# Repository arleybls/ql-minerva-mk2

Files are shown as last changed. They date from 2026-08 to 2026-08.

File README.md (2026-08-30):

# Sinclair QL - Minerva MK II Reimagined (SMD edition)

A surface-mount redesign of the Minerva MK II ROM and clock board for the Sinclair QL, based on
[Alvaro Alea Fernandez's KiCad recreation](https://github.com/alvaroalea/QL_Minerva_MK2) of the
original 1990 QView board.

The board plugs into the QL's internal ROM socket. It replaces the QL's ROM with a 64 KB EPROM
holding the Minerva operating system, with Toolkit II in the upper 16 KB if you want it, and adds
a battery-backed PCF8583 real-time clock. The clock sits on an I2C port inside the ROM address
space, so the QL reads it with ordinary ROM reads.

<p>
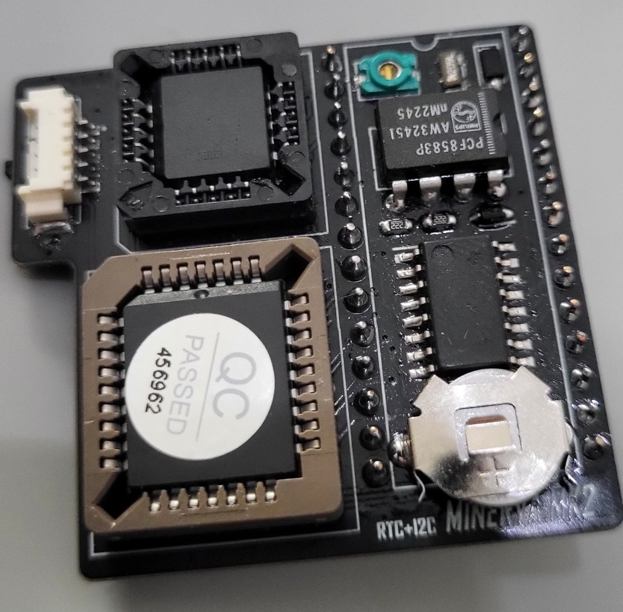
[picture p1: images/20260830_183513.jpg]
Assembled board
  
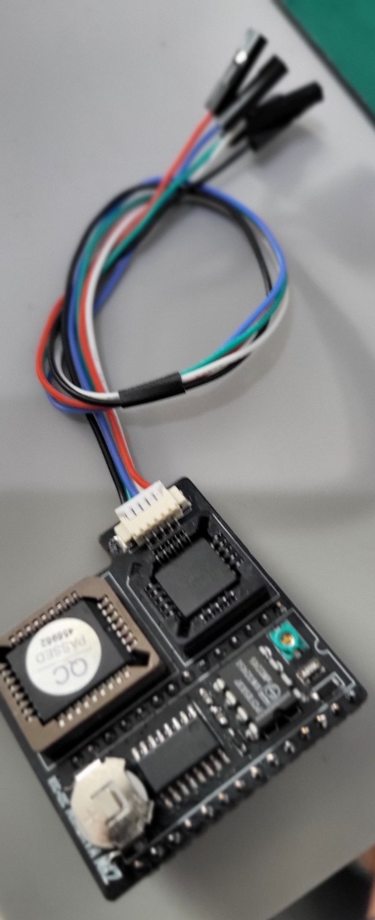
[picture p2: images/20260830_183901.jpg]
Assembled board with the I2C cable on J2
  
</p>

Left: the assembled board. Right: with the I2C cable plugged into J2.

## What is different from Alvaro's board

| | Alvaro's board | This board |
|---|---|---|
| Construction | through-hole | surface mount, 42.7 x 40.6 mm, two layers, ground pour on each side |
| EPROM | W27C512, DIP-28 socket, with the 74LS133 soldered underneath it | 27C512 in a PLCC-32 SMD socket; nothing mounted under anything |
| GAL16V8 | DIP-20 socket | PLCC-20 SMD socket, still reprogrammable |
| 13-input NAND | 74LS133, DIP-16 | SN74ALS133, SOP-16 |
| Resistors, diode, crystal, trimmer | axial, DO-35, AT310, radial trimmer | 0603, SOD-123W, FC-135, TZC3 SMD trimmer |
| Expansion header J2 | 2.54 mm pins | PicoBlade 53261 |
| Battery | external, through a two-pin header and a 120 ohm trickle-charge resistor | CR927 coin cell on the board, fed through two Schottky diodes so the cell is never charged and takes over when the QL is off |
| GAL pins 6 and 7 | pin 6 on VCC, pin 7 on /DECODE | pin 6 on SW1, pin 7 on +5 V, as the MINGAL_MH v1.10 equations require; this makes the map-in/map-out of the upper 16 KB work |
| Upper 16 KB select | JP1 solder jumper | SW1 slide switch (see below) |
| Decoupling | two capacitors | four 100 nF: at the GAL, the 74ALS133 and the EPROM on +5 V, and one at the PCF8583 on the battery rail |
| Clock chip testing | none | a small tester board and sketch (see below) |

### A switch instead of a solder jumper

Upstream JP1 was a three-pad solder jumper with its centre pad on the /DECODE net, which is the
74LS133's output. Pads 1 and 2 were bridged by default, so the jumper shorted that output to the
supply. SW1, a slide switch on its own GAL input, replaces it. SW1 selects whether the EPROM's
upper 16 KB (Toolkit II) is mapped in or left free for an external expansion ROM.

### A tester for the clock chips

`pcf8583-tester/` is a small separate board (Arduino Nano plus a DIP-8 socket) and a sketch for
checking PCF8583 chips before one is soldered in. It writes ten test patterns to all 248 bytes
of RAM, checks the clock registers, then drives the chip's oscillator input from the Nano at 100
times real speed to run the whole counter chain: minute, hour, month, leap-year rollovers, the
alarm and the timer. It prints a checklist and a pass or fail verdict in about three seconds.
Second-hand and old-stock PCF8583s vary a lot in quality, and this finds the bad ones. See
[pcf8583-tester/README.md](pcf8583-tester/README.md).

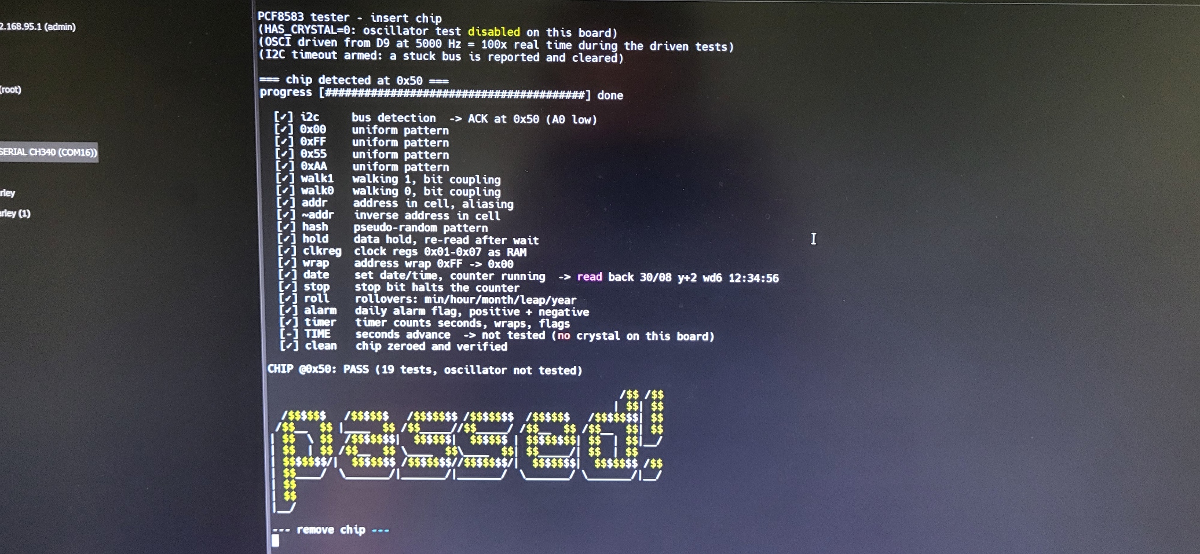
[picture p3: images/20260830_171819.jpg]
Tester output on the serial monitor: all tests passed


## Repository layout

```
QL_Minerva_MK2.kicad_sch / .kicad_pcb / .kicad_pro   the board (KiCad 10)
gerber/                                              fabrication files for the current board
bom/ibom.html                                        interactive BOM
images/                                              photos
pcf8583-tester/                                      clock chip tester: KiCad project, gerbers, sketch, README
```

The ROM image and the GAL files are not in this repository. They are the work of their
original authors; the next two sections say where to get them and how to prepare them.

## Getting the GAL code

The GAL16V8 needs the MINGAL_MH v1.10 fuse map (`MINGAL_MH_v110.jed`). Alvaro's README says
where his copy came from:

> Main information, GAL code, pictures, etc... has been obtained from this post:
> https://qlforum.co.uk/viewtopic.php?t=1993

That thread on qlforum.co.uk has the JEDEC file, the equations and the history of the v1.00
and v1.10 versions. Program the `.jed` into a GAL16V8 (or an ATF16V8) with any GAL programmer,
for example a TL866 with minipro or Xgpro.

## Building the ROM image with Toolkit II

The 27C512 holds a 1:1 image of the QL's ROM area:

```
0x0000-0xBFFF   Minerva 1.98a1 operating system (48 KB)
0xC000-0xFFFF   Toolkit II 2.36 (16 KB), in the QL's expansion ROM slot
```

The 64 KB image is nothing more than the two files joined, Minerva first.

1. Get Minerva 1.98a1 (the 48 KB ROM file) from Tony Firshman's Minerva page:
   http://tfs.firshman.co.uk/ql/minerva.htm
2. Get the Toolkit II v2.36 ROM image (16 KB) from Dilwyn Jones' site:
   https://dilwyn.qlforum.co.uk/docs/manuals/index.html (Toolkit II section).
3. Check the sizes: Minerva must be exactly 49,152 bytes and Toolkit II 16,384 bytes.
   If the Toolkit II file is shorter, pad it with 0xFF to 16,384 bytes.
4. Join them.

   Linux or macOS:

   ```
   cat Minerva_1.98a1.bin TK2_2.36.rom > Minerva_1.98a1_plus_TK2_2.36.bin
   ```

   Windows (PowerShell):

   ```
   cmd /c copy /b Minerva_1.98a1.bin+TK2_2.36.rom Minerva_1.98a1_plus_TK2_2.36.bin
   ```

   The result must be exactly 65,536 bytes.
5. Burn the 64 KB file into the 27C512 and set SW1 so the upper 16 KB is mapped in.

If you do not want Toolkit II, burn the 48 KB Minerva file on its own (the programmer fills the
rest of the EPROM with 0xFF) and set SW1 so the upper 16 KB is left free for an expansion ROM.

The last four bytes of the Minerva image (0xBFDC-0xBFDF) are the clock's I2C window. The GAL
intercepts reads there, so whatever the EPROM holds at those addresses is never seen; Minerva
reserves them for this purpose.

## Building one

1. Order the board from `gerber/`.
2. Fit the SMD parts, the two PLCC sockets and the CR927 holder. U1 is a 28-pin header row
   mounted on the solder side so the board can be plugged into the QL's ROM socket.
3. Program a GAL16V8 with `MINGAL_MH_v110.jed` and a 27C512 with the Minerva image, with or
   without Toolkit II (see the two sections above).
4. If the PCF8583 is not a new part, run it through the tester first, then fit it.
5. Set SW1: Toolkit II mapped in (64 KB image), or upper 16 KB left free for an expansion ROM.
6. Fit the cell, plug the board into the QL's ROM socket and power up.

## Licence

CERN Open Hardware Licence Version 2, Strongly Reciprocal (CERN-OHL-S v2), the same licence
as Alvaro's repository. The full text is in [LICENSE](LICENSE). The Minerva MK II design, the
Minerva OS and the GAL equations remain the work of their original authors. This repository
only carries the redesigned board.

Board redesign and tester (c) 2026 Arley Silveira. KiCad capture of the original (c) 2024
Alvaro Alea Fernandez.

Source location: https://github.com/arleybls/ql-minerva-mk2

Modification notice (CERN-OHL-S 3.3b): in 2025-2026 Arley Silveira converted Alvaro Alea
Fernandez's through-hole design to surface mount, added the on-board battery, rewired GAL pins
6 and 7, replaced JP1 with SW1, added decoupling and wrote the PCF8583 tester.

## References

- Alvaro's repository: https://github.com/alvaroalea/QL_Minerva_MK2
- Minerva at Tony Firshman's site: http://tfs.firshman.co.uk/ql/minerva.htm
- Minerva on the QL wiki: https://wiki.qlforum.co.uk/doku.php?id=qlwiki:minerva
- Manuals and software: https://dilwyn.qlforum.co.uk/docs/manuals/index.html
- Minerva MK II forum thread with the GAL code, pictures and history: https://qlforum.co.uk/viewtopic.php?t=1993

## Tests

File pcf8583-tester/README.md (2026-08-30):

# PCF8583 tester

Go/no-go tester for PCF8583 real-time-clock/RAM chips, built to screen chips
before fitting one to the QL Minerva MK2 board.

Insert a chip in the socket, the test runs by itself and prints a checklist and
a verdict on the serial port. Remove the chip, insert the next one.

Tester output on the serial monitor: all tests passed

## Contents

| Path | What |
|---|---|
| `RTC Tester.kicad_sch` / `.kicad_pcb` / `.kicad_pro` | KiCad 9 project: Arduino Nano, DIP-8 socket for the PCF8583, two 2.2 kΩ I2C pull-ups |
| `gerbers/` | Fabrication files for the board above |
| `pcf8583-tester-sketch/pcf8583-tester-sketch.ino` | Arduino sketch |

## Hardware

Board as designed:

| PCF8583 pin | Net |
|---|---|
| 1 OSCI | not connected |
| 2 OSCO | not connected |
| 3 A0 | not connected |
| 4 VSS | GND |
| 5 SDA | Nano A4, 2.2 kΩ to +5 V |
| 6 SCL | Nano A5, 2.2 kΩ to +5 V |
| 7 INT | not connected |
| 8 VDD | +5 V |

Two bodge wires are needed on the current board revision:

1. **A0 to VSS** — socket pin 3 to pin 4. Without it A0 floats, the chip's
   I2C address flickers between 0x50 and 0x51 and results are unreliable.
2. **Nano D9 to OSCI** — socket pin 1. The Nano generates the clock that
   drives the chip's counter chain (see *Driven tests* below). Optional: without
   it set `HAS_OSC_DRIVE` to 0 and the driven tests are skipped.

There is no crystal and no battery on this board, so the chip's own oscillator
and battery retention are not tested. See *Limits*.

## Flashing the Nano

Arduino IDE 2:

1. Open `pcf8583-tester-sketch/pcf8583-tester-sketch.ino`.
2. Tools → Board → Arduino AVR Boards → **Arduino Nano**.
3. Tools → Processor → **ATmega328P (Old Bootloader)** for a clone Nano
   (plain **ATmega328P** for a genuine one; switch if upload reports "not in sync").
4. Tools → Port → the Nano's COM port.
5. Upload.

Or with `arduino-cli`:

```
arduino-cli compile --upload --fqbn arduino:avr:nano:cpu=atmega328old -p COMx pcf8583-tester-sketch
```

Only the built-in `Wire` library is used.

## Using it

1. Open the Serial Monitor at **115200 baud**. You should see:

   ```
   PCF8583 tester - insert chip
   (HAS_CRYSTAL=0: oscillator test disabled on this board)
   (OSCI driven from D9 at 5000 Hz = 100x real time)
   ```

   While no chip is present a `.` is printed every 5 s as a heartbeat.

2. Insert a chip, pin 1 towards the socket notch. The test starts within
   0.5 s and takes about 3 s. Output:

   ```
   === chip detected at 0x50 ===
   progress [######################################] done

     [✓] i2c     bus detection  -> ACK at 0x50 (A0 low)
     [✓] 0x00    uniform pattern
     [✓] 0xFF    uniform pattern
     [✓] 0x55    uniform pattern
     [✓] 0xAA    uniform pattern
     [✓] walk1   walking 1, bit coupling
     [✓] walk0   walking 0, bit coupling
     [✓] addr    address in cell, aliasing
     [✓] ~addr   inverse address in cell
     [✓] hash    pseudo-random pattern
     [✓] hold    data hold 2 s
     [✓] clkreg  clock regs 0x01-0x07 as RAM
     [✓] wrap    address wrap 0xFF -> 0x00
     [✓] date    set date/time, counter running  -> read back 30/08 y+2 wd6 12:34:56
     [✓] roll    rollovers: min/hour/month/leap/year
     [✓] alarm   daily alarm flag
     [✓] timer   timer counts seconds
     [-] TIME    seconds advance  -> not tested (no crystal on this board)
     [✓] clean   chip zeroed

   CHIP @0x50: PASS (18 tests, oscillator not tested)
   ```

   followed by a large "passed!" banner. A failing chip prints
   `CHIP @0x50: FAIL (n of 18 tests failed)` instead, with details on the
   failing rows (see *Reading failures*).

3. Remove the chip. The tester prints `insert next chip` and re-arms.

The chip is hot-plugged with the Nano powered. That is normally harmless for
this CMOS part; if you prefer, power the Nano off between chips — the test
runs on power-up the same way.

## What is tested

The chip's memory map: 0x00 control/status, 0x01–0x07 clock counters,
0x08–0x0F alarm registers, 0x10–0xFF 240 bytes free RAM. Everything from 0x08
up is tested as RAM (the Minerva ROM may use the alarm area as storage).

### I2C

| Row | Check |
|---|---|
| `i2c` | Chip ACKs at 0x50 (A0 low) or 0x51 (A0 high). Answering at **both** is a fault: A0 floating or the chip's A0 input broken. The address found is reported. |

Every read and write in every test checks the I2C result. A NAK or short read
marks that test `BUS ERROR @0x..`, and the remaining tests are skipped, so a
bus problem can never be mistaken for a memory fault.

### RAM march, 0x08–0xFF (248 bytes)

Each pass writes the whole range then reads it all back.

| Row | Pattern | Catches |
|---|---|---|
| `0x00` `0xFF` `0x55` `0xAA` | uniform | stuck bits, shorted adjacent bits |
| `walk1` | one bit set per byte, rotating with address | bit-to-bit coupling within a byte |
| `walk0` | one bit cleared per byte, rotating | same, opposite polarity |
| `addr` | each cell holds its own address | address-line faults: two addresses hitting one cell |
| `~addr` | inverse of its address | same, opposite polarity |
| `hash` | pseudo-random function of the address | pattern-sensitive cells |
| `hold` | the `hash` pattern re-read after 2 s | cells that leak |

### Registers

| Row | Check |
|---|---|
| `clkreg` | 0x01–0x07 written with 0x55/0xAA patterns and read back while the counter is stopped (control bit 7). |
| `wrap` | A 2-byte read starting at 0xFF must return 0xFF then 0x00 (control register): the address auto-increment wraps. |
| `date` | Control = 0x00 (clock mode, running), the way the Minerva ROM uses it. Writes 30 August, year+2, Sunday, 12:34:56 in the datasheet register layouts, waits 300 ms, reads everything back and checks every field. The decoded read-back is printed. |

### Driven tests (`HAS_OSC_DRIVE`)

The PCF8583 has a "50 Hz" mode (control bits 5:4 = 01) that clocks the counter
chain from an external signal on OSCI instead of the crystal. The Nano drives
OSCI at 5 kHz with `tone()`, so the clock runs at 100× real time: one chip
second is 10 ms. This exercises every part of the RTC logic except the crystal
oscillator itself.

| Row | Check |
|---|---|
| `roll` | Seven rollover cases. Each sets the clock at hh:mm:58 plus a date, waits 2.5 chip-seconds, and checks minutes, hours, date, month, weekday and year: |

| Case | Set | Expect |
|---|---|---|
| 1 | 12:34:58 | 12:35 |
| 2 | 12:59:58 | 13:00 |
| 3 | 23:59:58 30 Apr | 00:00 01 May, weekday +1 |
| 4 | 23:59:58 31 May | 01 Jun |
| 5 | 23:59:58 28 Feb, year+1 | 01 Mar (non-leap) |
| 6 | 23:59:58 28 Feb, year+0 | 29 Feb (the chip's year 0 is the leap year) |
| 7 | 23:59:58 31 Dec, year+3 | 01 Jan, year+0 (year counter wraps) |

| Row | Check |
|---|---|
| `alarm` | Clock 12:34:58, daily alarm 12:35:00, alarm enabled. The alarm flag must be clear right after arming and set 3.5 chip-seconds later. |
| `timer` | Timer function = seconds, timer register = 00. Must read 03 or 04 after 3.5 chip-seconds. |

### Oscillator (`HAS_CRYSTAL`)

| Row | Check |
|---|---|
| `TIME` | Only with a crystal fitted: set 12:34:56 in normal 32.768 kHz mode, wait 2.5 s, seconds must have advanced. Shown as `[-] not tested` on this board. |

### Cleanup

| Row | Check |
|---|---|
| `clean` | 0x01–0xFF zeroed and control register set to 0x00, so a passing chip goes into a Minerva blank. Counts as a test because it is a final write pass. |

## Reading failures

Each failing row prints the first mismatch:

```
  [✗] addr    address in cell, aliasing  -> FAIL @0x41 expected 0x41 got 0x40 bad bits 0x01, 12 bytes
```

* `@0x41` — register address of the first bad byte.
* `bad bits` — XOR of expected and actual: which bits are wrong.
* `12 bytes` — total bad bytes in that pass.

For `roll` the address is replaced by the case number and register:

```
  [✗] roll    rollovers: min/hour/month/leap/year  -> FAIL case 6 reg 0x05 expected 0x29 got 0x01
```

(case 6 = leap-year February, register 0x05 = year/date; here the chip treated
year 0 as non-leap.)

Rules of thumb:

* Same bit wrong across many addresses → stuck data line or bad output driver.
* `addr` / `~addr` fail while the uniform patterns pass → address decoding fault.
* Only `hold` fails → leaky cells; the chip may work but will not keep data on
  battery.
* `BUS ERROR` mid-run on a chip that was detected → poor socket contact, or the
  A0 bodge is missing and the address flickered. Re-seat and retry before
  blaming the chip.
* `i2c` reports 0x51 → chip works but A0 is high: the bodge is missing.

## Configuration

At the top of the sketch:

| Define | Default | Meaning |
|---|---|---|
| `HAS_CRYSTAL` | 0 | 1 on a board with a 32.768 kHz crystal: enables `TIME` and lets `date` tolerate ticking seconds |
| `HAS_OSC_DRIVE` | 1 | 1 with the D9→OSCI wire: enables `roll`, `alarm`, `timer` |
| `OSC_PIN` | 9 | Nano pin driving OSCI |
| `OSC_HZ` | 5000 | drive frequency; speed-up factor is `OSC_HZ / 50` |
| `HOLD_MS` | 2000 | wait for the `hold` pass |
| `CHUNK` | 16 | bytes per I2C transaction (Wire buffer is 32) |

Serial is 115200 baud, I2C 100 kHz (the PCF8583 maximum).

## Limits

A PASS here means: good RAM, good I2C interface, good counter/calendar/alarm
logic. It does **not** prove:

* the on-chip oscillator amplifier works with a real crystal (`TIME`, needs a
  crystal on the board);
* the chip keeps time and RAM on battery (needs a battery and a retention test).

Both are planned for a board revision with a 32.768 kHz crystal, trimmer, A0
tied to ground and a backup battery with diode.

## History

The first version of this sketch tested a single RAM byte at a hard-coded
address 0x50 without checking I2C results. With A0 floating on the board, the
chip's address drifted between 0x50 and 0x51 and good chips were reported as
bad. If you have chips rejected by that version, re-test them.

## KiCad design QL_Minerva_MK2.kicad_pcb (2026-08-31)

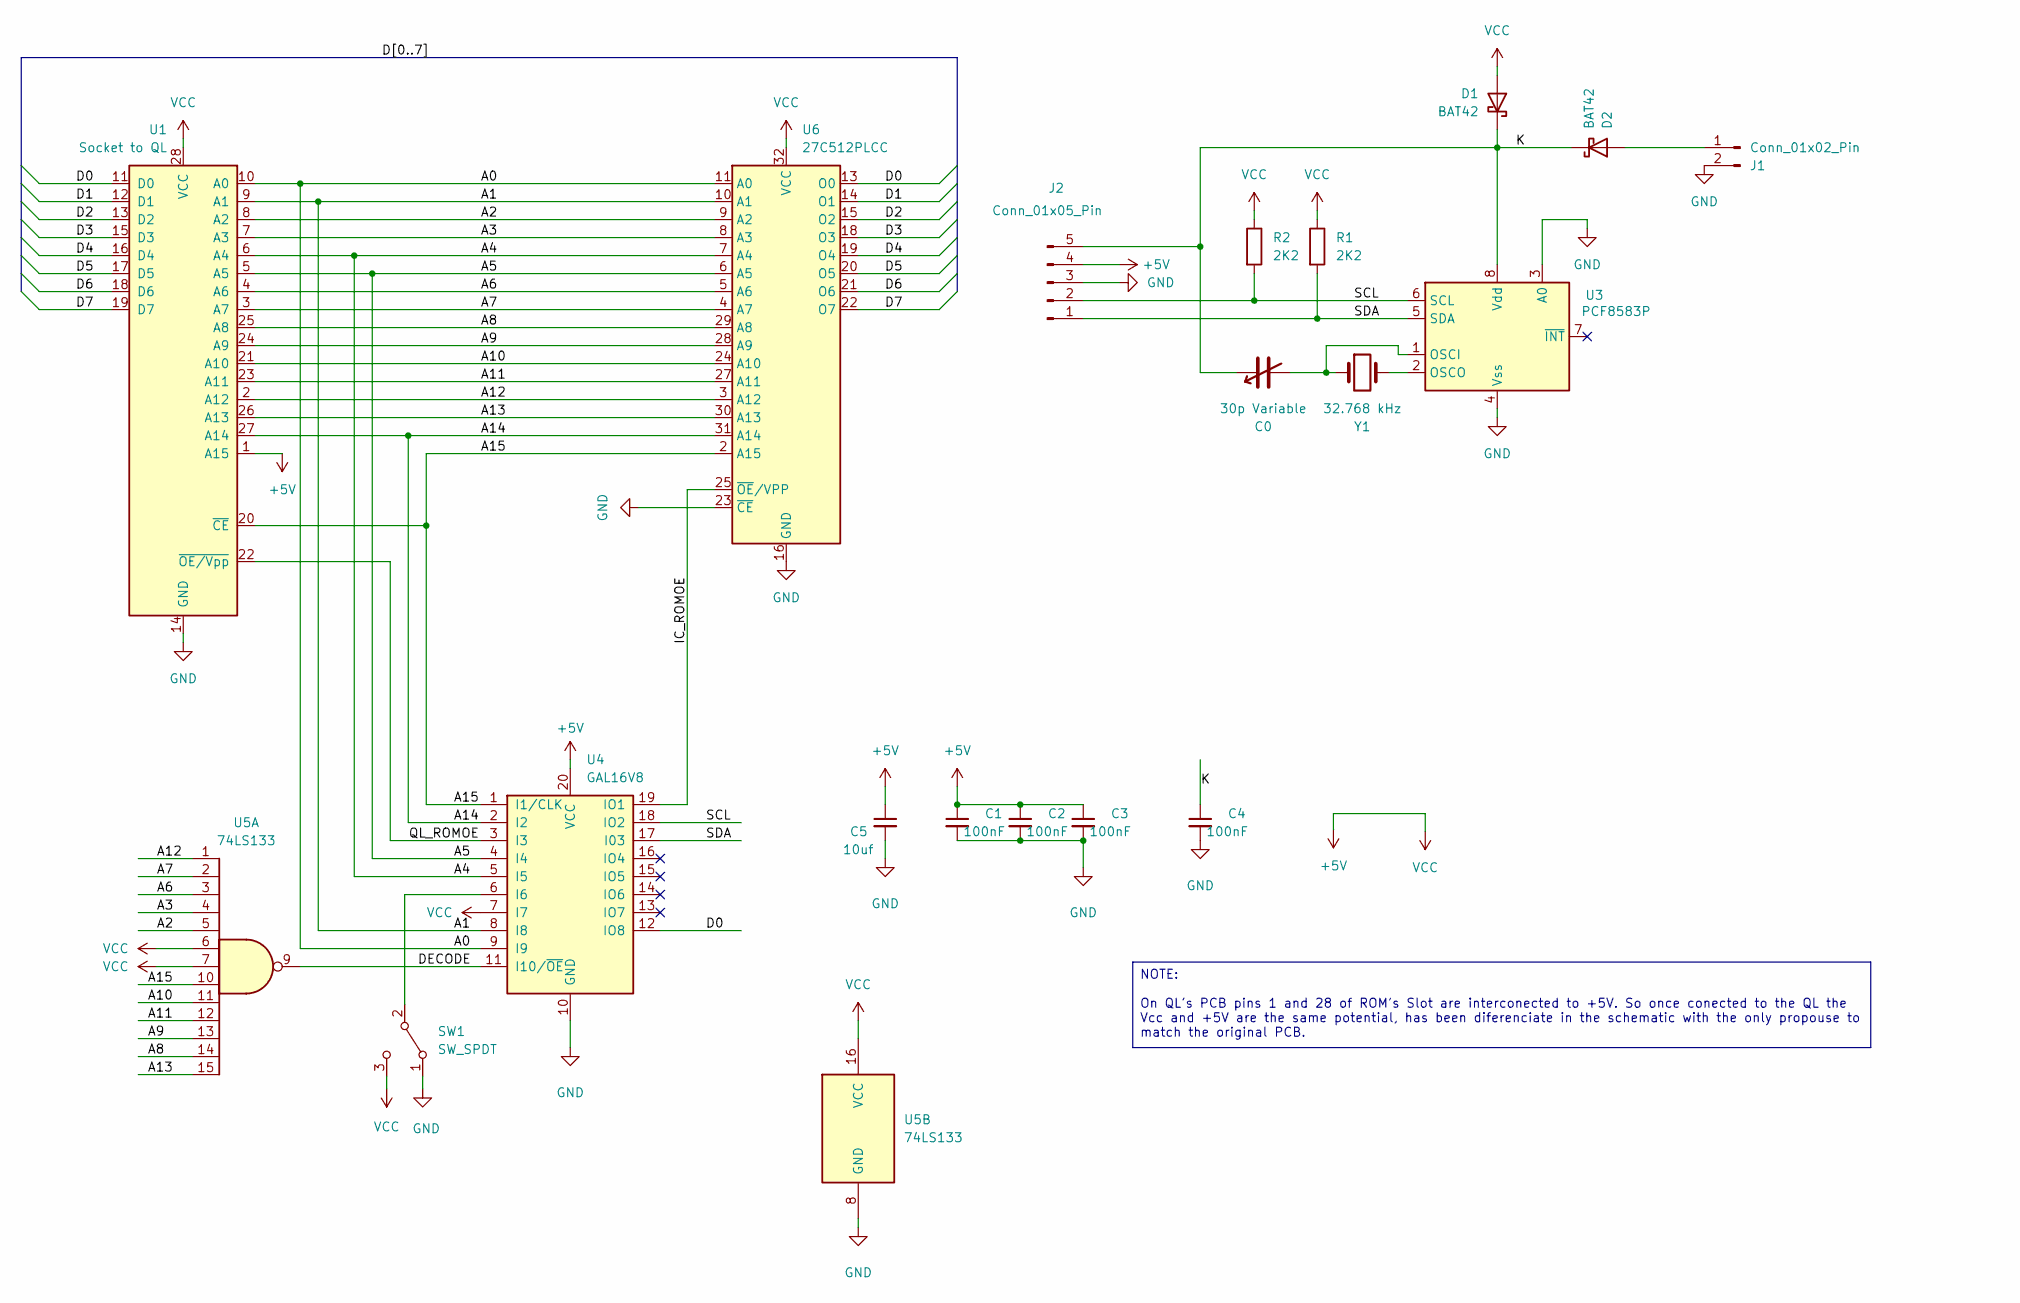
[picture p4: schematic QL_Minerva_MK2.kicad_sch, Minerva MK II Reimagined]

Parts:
C0: 30p Variable; TZC3_MUR
C1, C2, C3, C4: 100nF; C_0603_1608Metric
C5: 10uf; C_0805_2012Metric
D1: BAT42; Nexperia_CFP3_SOD-123W
D2: BAT42; BAT42WS
J1: Conn_01x02_Pin; CR927Holder
J2: Conn_01x05_Pin; PicoBlade_53261
R1, R2: 2K2; R_0603_1608Metric
SW1: SW_SPDT; SW_SPDT_PCM12
U1: Socket to QL; DIP-28_W15.24mm
U3: PCF8583P; DIP-8_W7.62mm
U4: GAL16V8; PLCC-20_SMD-Socket
U5: 74LS133; SN74ALS133NSR
U6: 27C512PLCC; CONN_PLCC-32-AT-SMT_ADM
Y1: 32.768 kHz; XTAL_FC-135_32.7680KA-A0

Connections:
+5V: C1.1, C2.1, C3.1, C5.1, D1.2 (A), J2.4, R1.1, R2.1, SW1.3 (C), U1.1 (A15), U1.28 (VCC), U4.7 (I7), U4.20 (VCC), U5.6, U5.7, U5.16 (VCC), U6.32 (VCC)
/A0: U1.10 (A0), U4.9 (I9), U6.11 (A0)
/A1: U1.9 (A1), U4.8 (I8), U6.10 (A1)
/A2: U1.8 (A2), U5.5, U6.9 (A2)
/A3: U1.7 (A3), U5.4, U6.8 (A3)
/A4: U1.6 (A4), U4.5 (I5), U6.7 (A4)
/A5: U1.5 (A5), U4.4 (I4), U6.6 (A5)
/A6: U1.4 (A6), U5.3, U6.5 (A6)
/A7: U1.3 (A7), U5.2, U6.4 (A7)
/A8: U1.25 (A8), U5.14, U6.29 (A8)
/A9: U1.24 (A9), U5.13, U6.28 (A9)
/A10: U1.21 (A10), U5.11, U6.24 (A10)
/A11: U1.23 (A11), U5.12, U6.27 (A11)
/A12: U1.2 (A12), U5.1, U6.3 (A12)
/A13: U1.26 (A13), U5.15, U6.30 (A13)
/A14: U1.27 (A14), U4.2 (I2), U6.31 (A14)
/A15: U1.20 (~CE), U4.1 (I1/CLK), U5.10, U6.2 (A15)
/D0: U1.11 (D0), U4.12 (IO8), U6.13 (O0)
/D1: U1.12 (D1), U6.14 (O1)
/D2: U1.13 (D2), U6.15 (O2)
/D3: U1.15 (D3), U6.18 (O3)
/D4: U1.16 (D4), U6.19 (O4)
/D5: U1.17 (D5), U6.20 (O5)
/D6: U1.18 (D6), U6.21 (O6)
/D7: U1.19 (D7), U6.22 (O7)
/DECODE: U4.11 (I10/~OE), U5.9
/IC_ROMOE: U4.19 (IO1), U6.25 (~OE/VPP)
/K: C0.1, C4.1, D1.1 (K), D2.1 (K), J2.5, U3.8 (Vdd)
/QL_ROMOE: U1.22 (~OE/Vpp), U4.3 (I3)
/SCL: J2.2, R2.2, U3.6 (SCL), U4.18 (IO2)
/SDA: J2.1, R1.2, U3.5 (SDA), U4.17 (I03)
GND: C1.2, C2.2, C3.2, C4.2, C5.2, J1.2, J2.3, SW1.1 (A), U1.14 (GND), U3.3 (A0), U3.4 (Vss), U4.10 (GND), U5.8 (GND), U6.16 (GND), U6.23 (~CE)
unnamed: D2.2 (A), J1.1
unnamed: SW1.2 (B), U4.6 (I6)
unnamed: C0.2, U3.1 (OSCI), Y1.1
unnamed: U3.2 (OSCO), Y1.2

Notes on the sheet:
NOTE: On QL's PCB pins 1 and 28 of ROM's Slot are interconected to +5V. So once conected to the QL the Vcc and +5V are the same potential, has been diferenciate in the schematic with the only propouse to match the original PCB.

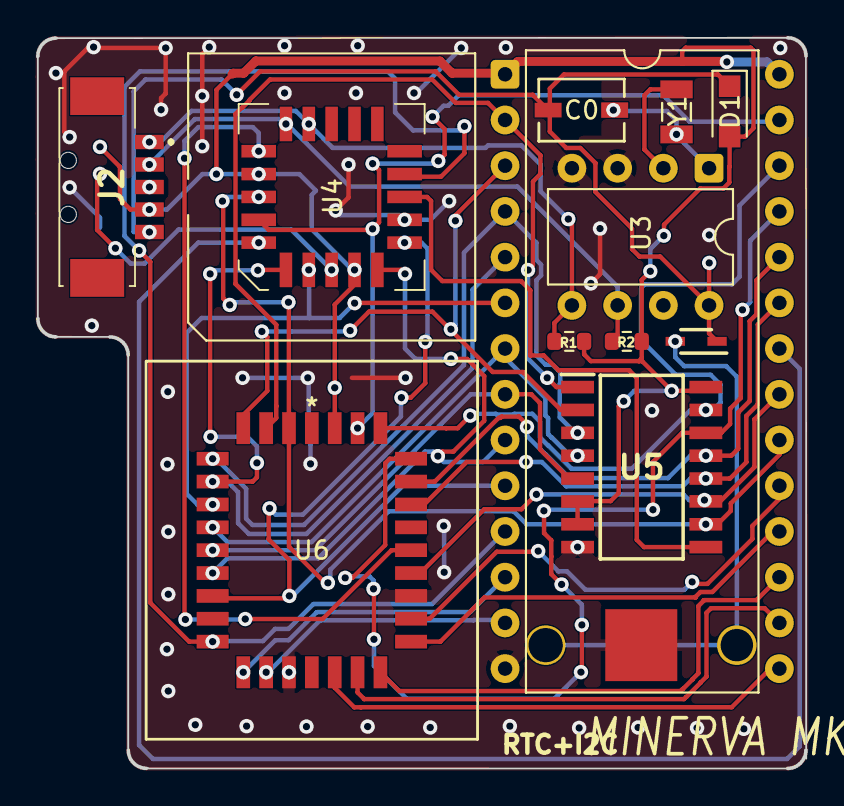
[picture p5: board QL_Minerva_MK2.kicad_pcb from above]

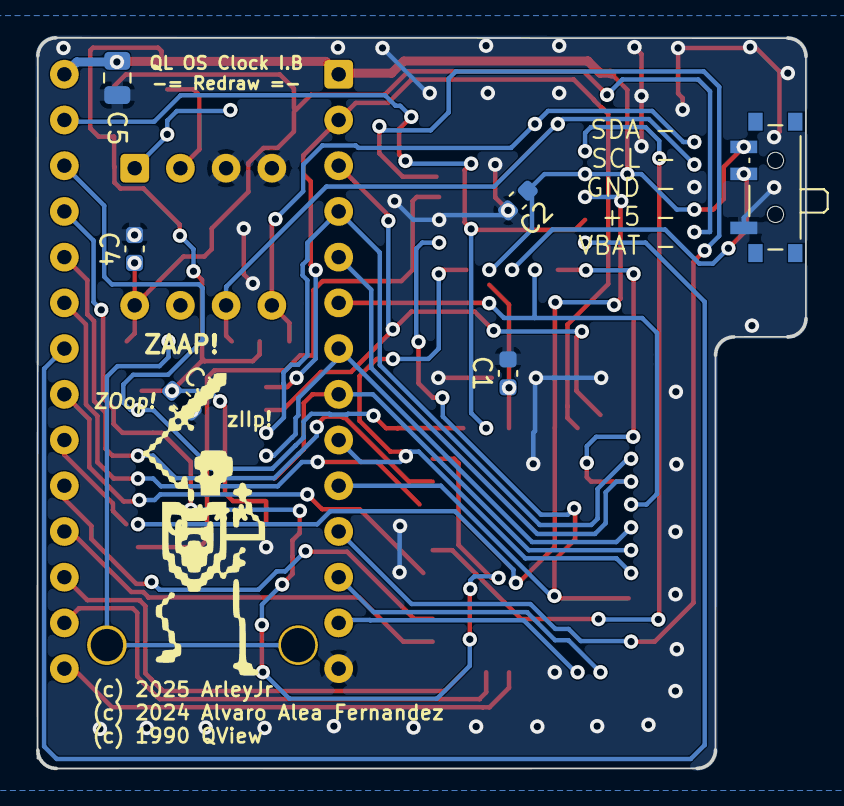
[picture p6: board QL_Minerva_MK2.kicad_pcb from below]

Board: 2 copper layers, 42.7 x 40.6 mm, 19 parts (6 on the bottom side), 36 nets.

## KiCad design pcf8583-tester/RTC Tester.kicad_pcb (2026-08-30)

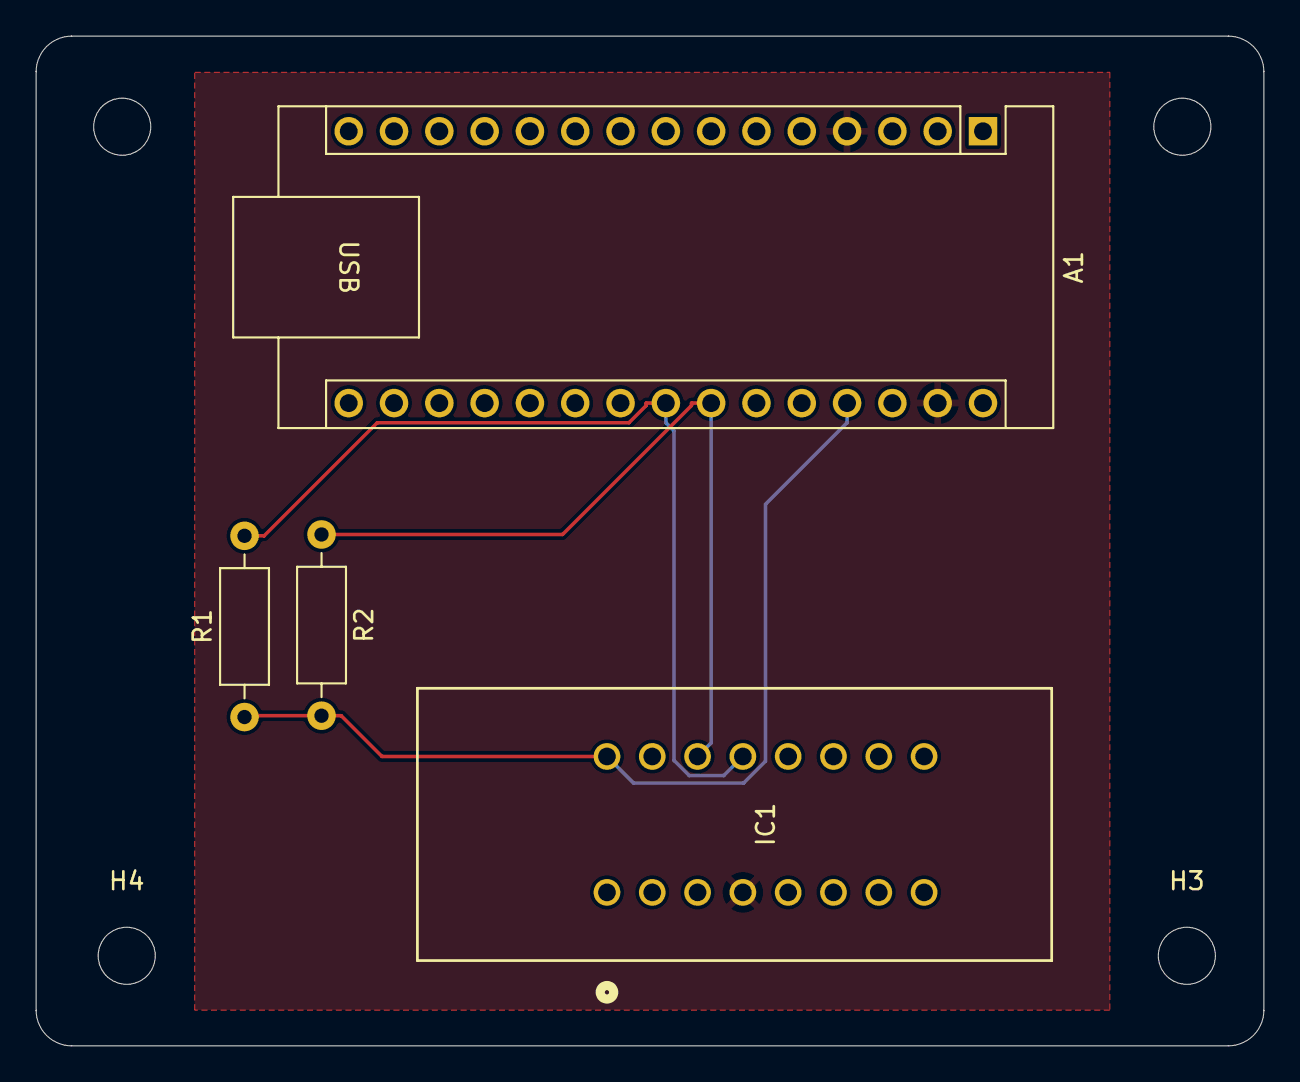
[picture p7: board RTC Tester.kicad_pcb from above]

Board: 2 copper layers, 68.8 x 56.6 mm, 8 parts (0 on the bottom side), 4 nets.

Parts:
A1: Arduino_Nano_v3.x; Arduino_Nano
H1, H2, H3, H4: MountingHole; MountingHole_3.2mm_M3
IC1: PCF8583P_F5,112; ZIF16_TO_PCF8583
R1, R2: 2.2K; R_Axial_DIN0207_L6.3mm_D2.5mm_P10.16mm_Horizontal

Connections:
+5V: A1.27 (+5V), IC1.8 (VDD), R1.1, R2.2
GND: A1.4 (GND), A1.29 (GND), IC1.4 (VSS)
unnamed: A1.23 (A4), IC1.5 (SDA), R1.2
unnamed: A1.24 (A5), IC1.6 (SCL), R2.1

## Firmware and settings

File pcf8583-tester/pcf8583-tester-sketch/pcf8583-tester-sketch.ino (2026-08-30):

// PCF8583 go/no-go tester
//
// Copyright (c) 2026 Arley Silveira
// All rights reserved.
//
// Continuous mode: insert a chip in the socket, the test runs by itself,
// shows a progress bar, then a checklist and a verdict; remove the chip and
// insert the next one.
//
// RAM passes over 0x08..0xFF (alarm registers + 240 bytes free RAM):
//   0x00 0xFF 0x55 0xAA  uniform patterns, stuck bits
//   walk1 walk0          one bit set / cleared per byte, rotating: bit coupling
//   addr ~addr           cell = its address / inverse: address-line aliasing
//   hash                 pseudo-random pattern: pattern-sensitive cells
//   hold                 hash pattern, wait HOLD_MS, re-read: leaky cells
// Extra checks:
//   clkreg               clock registers 0x01..0x07 as RAM, counter stopped
//   wrap                 address counter wraps 0xFF -> 0x00
//   date                 set 30/08 y+2 12:34:56 with the counter running, read back
// With HAS_OSC_DRIVE = 1 (Nano pin OSC_PIN wired to OSCI, chip in 50 Hz mode,
// driven at OSC_HZ so the clock runs OSC_HZ/50 times faster than real time).
// The drive is only on during these tests, never while a chip is inserted:
//   stop                 control bit 7 halts the counter
//   roll                 7 rollover cases: minute, hour, 30/31-day month,
//                        February non-leap and leap, year-end + year counter
//   alarm                daily alarm flag sets at the alarm time, not at another time
//   timer                timer register counts seconds, wraps 99 -> 00, sets its flag
//   TIME                 only with HAS_CRYSTAL = 1: set 12:34:56, check seconds advance
//   clean                counter stopped, 0x01..0xFF zeroed and read back, control 0x00
//
// Board notes: A0 must be tied to VSS (bodge pin 3 -> pin 4 on the socket).
// The chip answers at 0x50 with A0 low, 0x51 with A0 high; both are scanned.
// OSCI drive: wire Nano D9 (OSC_PIN) to socket pin 1 (OSCI).

#include <Wire.h>

// The AVR core has had Wire.setWireTimeout() since 1.8.3 but only newer cores
// announce it with WIRE_HAS_TIMEOUT.
#if defined(WIRE_HAS_TIMEOUT) || defined(ARDUINO_ARCH_AVR)
#define HAVE_WIRE_TIMEOUT 1
#endif

// ---------------------------------------------------------------- configuration

#define HAS_CRYSTAL     0        // 1 on a board with a 32.768 kHz crystal
#define HAS_OSC_DRIVE   1        // 1 with a wire from OSC_PIN to OSCI (pin 1)
#define OSC_PIN         9
#define OSC_HZ          5000UL   // 50 Hz mode: 50 pulses = 1 chip second -> 100x real time
#define CHIP_MS(tenths) ((tenths) * 5000UL / OSC_HZ)   // real ms for N tenths of a chip second

#define CHUNK           31       // data bytes per I2C transaction (Wire buffer 32 = reg + 31)
#define HOLD_MS         2000     // wait for the hold pass
#define DATE_SETTLE_MS  300      // wait between setting and reading back the date
#define POLL_MS         500      // idle poll interval
#define SETTLE_MS       200      // socket contacts settle after insertion
#define HEARTBEAT_POLLS 10       // one '.' every 10 polls = 5 s while idle
#define WIRE_TIMEOUT_US 25000UL  // a stuck bus returns an error instead of hanging

// ---------------------------------------------------------------- PCF8583

#define ADDR_A0_LOW   0x50
#define ADDR_A0_HIGH  0x51

#define REG_CONTROL   0x00
#define REG_HUNDREDTH 0x01
#define REG_SECONDS   0x02
#define REG_MINUTES   0x03
#define REG_HOURS     0x04
#define REG_YEARDATE  0x05
#define REG_WDMONTH   0x06
#define REG_TIMER     0x07
#define REG_ALARM_CTL 0x08
#define RAM_START     REG_ALARM_CTL
#define RAM_END       0xFF

#define CTL_STOP      0x80     // bit 7: stop counting and reset the divider
#define CTL_50HZ      0x10     // bits 5-4 = 01: clock mode clocked from OSCI at 50 Hz
#define CTL_ALARM_EN  0x04     // bit 2: enable the alarm function (alarm control + timer)
#define CTL_ALARM_FLG 0x02     // bit 1: alarm flag (when alarm enabled)
#define CTL_TIMER_FLG 0x01     // bit 0: timer flag (when alarm enabled)
#define ALM_DAILY     0x10     // alarm control bits 5-4 = 01: daily alarm
#define ALM_TMR_SEC   0x02     // alarm control bits 2-0 = 010: timer counts seconds

// Register bit layouts
#define YD(y, d)  (((y) << 6) | (d))     // 0x05: year 0-3 (0 = leap), BCD date
#define WM(wd, m) (((wd) << 5) | (m))    // 0x06: weekday 0-6, BCD month
// 0x04: bit 7 = 12 h format (0 = 24 h), bit 6 = AM/PM, bits 5-0 BCD hours

// ---------------------------------------------------------------- tests

enum Test : byte {
  T_I2C,
  T_00, T_FF, T_55, T_AA, T_WALK1, T_WALK0, T_ADDR, T_NADDR, T_HASH, T_HOLD,
  T_CLKREG, T_WRAP, T_DATE,
  T_STOP, T_ROLL, T_ALARM, T_TIMER,     // OSCI-driven
  T_TIME, T_CLEAN, N_TESTS
};
#define IS_RAM_PASS(t) ((t) >= T_00 && (t) <= T_HOLD)
static_assert(T_HOLD == T_HASH + 1, "hold re-reads the hash pattern left by the previous pass");

enum Status : byte { S_PENDING, S_OK, S_FAIL, S_BUS, S_NT, S_SKIP };

struct TestResult {
  Status status;
  byte addr, expect, got;   // first failure
  byte count;               // number of failing bytes
};

static TestResult results[N_TESTS];
static byte dev;            // I2C address of the chip under test
static byte curTest;        // test being run, for bus-error attribution
static bool bothAddr;       // chip answered at 0x50 and 0x51
static bool busDead;        // once a bus error happens, remaining tests are skipped
static byte dateBack[6];    // date test read-back for the checklist row

static const __FlashStringHelper *testName(byte t) {
  switch (t) {
    case T_I2C:    return F("i2c   ");
    case T_00:     return F("0x00  ");
    case T_FF:     return F("0xFF  ");
    case T_55:     return F("0x55  ");
    case T_AA:     return F("0xAA  ");
    case T_WALK1:  return F("walk1 ");
    case T_WALK0:  return F("walk0 ");
    case T_ADDR:   return F("addr  ");
    case T_NADDR:  return F("~addr ");
    case T_HASH:   return F("hash  ");
    case T_HOLD:   return F("hold  ");
    case T_CLKREG: return F("clkreg");
    case T_WRAP:   return F("wrap  ");
    case T_DATE:   return F("date  ");
    case T_STOP:   return F("stop  ");
    case T_ROLL:   return F("roll  ");
    case T_ALARM:  return F("alarm ");
    case T_TIMER:  return F("timer ");
    case T_TIME:   return F("TIME  ");
    case T_CLEAN:  return F("clean ");
    default:       return F("?     ");
  }
}

static const __FlashStringHelper *testDesc(byte t) {
  switch (t) {
    case T_I2C:    return F("bus detection");
    case T_00: case T_FF: case T_55: case T_AA: return F("uniform pattern");
    case T_WALK1:  return F("walking 1, bit coupling");
    case T_WALK0:  return F("walking 0, bit coupling");
    case T_ADDR:   return F("address in cell, aliasing");
    case T_NADDR:  return F("inverse address in cell");
    case T_HASH:   return F("pseudo-random pattern");
    case T_HOLD:   return F("data hold, re-read after wait");
    case T_CLKREG: return F("clock regs 0x01-0x07 as RAM");
    case T_WRAP:   return F("address wrap 0xFF -> 0x00");
    case T_DATE:   return F("set date/time, counter running");
    case T_STOP:   return F("stop bit halts the counter");
    case T_ROLL:   return F("rollovers: min/hour/month/leap/year");
    case T_ALARM:  return F("daily alarm flag, positive + negative");
    case T_TIMER:  return F("timer counts seconds, wraps, flags");
    case T_TIME:   return F("seconds advance");
    case T_CLEAN:  return F("chip zeroed and verified");
    default:       return F("");
  }
}

static byte patternByte(byte t, byte a) {
  switch (t) {
    case T_00:    return 0x00;
    case T_FF:    return 0xFF;
    case T_55:    return 0x55;
    case T_AA:    return 0xAA;
    case T_WALK1: return 1 << (a & 7);
    case T_WALK0: return ~(1 << (a & 7));
    case T_ADDR:  return a;
    case T_NADDR: return ~a;
    case T_HASH:
    case T_HOLD:  return (byte)((a * 0x9D + 0x3B) ^ (a << 3) ^ (a >> 5));
    default:      return 0;
  }
}

// ---------------------------------------------------------------- I2C

static void wireSetup() {
  Wire.begin();
  Wire.setClock(100000);   // PCF8583 is 100 kHz max
#ifdef HAVE_WIRE_TIMEOUT
  Wire.setWireTimeout(WIRE_TIMEOUT_US, true);
  Wire.clearWireTimeoutFlag();
#endif
}

// Free a slave that is holding SDA low: clock SCL up to 9 times, then a STOP.
static void busClear() {
  Wire.end();
  pinMode(SDA, INPUT_PULLUP);
  pinMode(SCL, INPUT_PULLUP);
  for (byte i = 0; i < 9 && digitalRead(SDA) == LOW; i++) {
    pinMode(SCL, OUTPUT); digitalWrite(SCL, LOW); delayMicroseconds(5);
    pinMode(SCL, INPUT_PULLUP);                    delayMicroseconds(5);
  }
  pinMode(SDA, OUTPUT); digitalWrite(SDA, LOW); delayMicroseconds(5);
  pinMode(SDA, INPUT_PULLUP);                    delayMicroseconds(5);
  wireSetup();
}

static bool busTimedOut() {
#ifdef HAVE_WIRE_TIMEOUT
  return Wire.getWireTimeoutFlag();
#else
  return false;
#endif
}

static bool chipPresent(byte a) {
  Wire.beginTransmission(a);
  return Wire.endTransmission() == 0;
}

static void setBus(byte reg) {
  results[curTest].status = S_BUS;
  results[curTest].addr = reg;
  busDead = true;
}

// Write n bytes at reg; on failure records a bus error for the current test.
static bool wr(byte reg, const byte *data, byte n) {
  Wire.beginTransmission(dev);
  Wire.write(reg);
  if (n) Wire.write(data, n);
  if (Wire.endTransmission() == 0) return true;
  setBus(reg);
  return false;
}

static bool wr1(byte reg, byte v) { return wr(reg, &v, 1); }

// Read n bytes from reg (repeated start); on failure records a bus error.
static bool rd(byte reg, byte *data, byte n) {
  Wire.beginTransmission(dev);
  Wire.write(reg);
  if (Wire.endTransmission(false) == 0 && Wire.requestFrom(dev, n) == n) {
    for (byte i = 0; i < n; i++) data[i] = Wire.read();
    return true;
  }
  setBus(reg);
  return false;
}

static void setFail(byte reg, byte expect, byte got) {
  TestResult &r = results[curTest];
  if (r.status != S_FAIL) { r.status = S_FAIL; r.addr = reg; r.expect = expect; r.got = got; }
  if (r.count < 255) r.count++;
}

static void printHex2(byte v) {
  if (v < 0x10) Serial.print('0');
  Serial.print(v, HEX);
}

// ---------------------------------------------------------------- OSCI drive

// Only driven during the driven tests: a chip must never be inserted with
// 5 V on OSCI, and a crystal (HAS_CRYSTAL) must be left alone otherwise.
static void oscDrive(bool on) {
#if HAS_OSC_DRIVE
  if (on) {
    tone(OSC_PIN, OSC_HZ);
  } else {
    noTone(OSC_PIN);
    pinMode(OSC_PIN, INPUT);
  }
#else
  (void)on;
#endif
}

// ---------------------------------------------------------------- RAM passes

static bool ramFill(byte t) {
  byte buf[CHUNK];
  for (int addr = RAM_START; addr <= RAM_END; addr += CHUNK) {
    byte n = min((int)CHUNK, RAM_END - addr + 1);
    for (byte i = 0; i < n; i++) buf[i] = patternByte(t, addr + i);
    if (!wr(addr, buf, n)) return false;
  }
  return true;
}

static void ramVerify(byte t) {
  byte buf[CHUNK];
  for (int addr = RAM_START; addr <= RAM_END; addr += CHUNK) {
    byte n = min((int)CHUNK, RAM_END - addr + 1);
    if (!rd(addr, buf, n)) return;
    for (byte i = 0; i < n; i++) {
      byte a = addr + i;
      byte expect = patternByte(t, a);
      if (buf[i] != expect) setFail(a, expect, buf[i]);
    }
  }
}

static void ramPass(byte t) {
  if (t == T_HOLD) {
    delay(HOLD_MS);              // hash pattern is still in RAM from the previous pass
  } else if (!ramFill(t)) {
    return;
  }
  ramVerify(t);
}

// ---------------------------------------------------------------- register tests

// Clock registers 0x01..0x07 are plain RAM cells when the counter is stopped.
static void clkregTest() {
  if (!wr1(REG_CONTROL, CTL_STOP)) return;
  const byte pats[2] = {0x55, 0xAA};
  for (byte p = 0; p < 2; p++) {
    byte w[7], back[7];
    for (byte i = 0; i < 7; i++) w[i] = pats[p] ^ (i & 1 ? 0xFF : 0x00);
    if (!wr(REG_HUNDREDTH, w, 7) || !rd(REG_HUNDREDTH, back, 7)) return;
    for (byte i = 0; i < 7; i++)
      if (back[i] != w[i]) setFail(REG_HUNDREDTH + i, w[i], back[i]);
  }
}

// Reading 2 bytes from 0xFF must wrap to 0x00 (control register).
static void wrapTest() {
  const byte ctl = CTL_STOP | CTL_50HZ;   // distinctive, stopped, no alarm function
  const byte last = 0x3C;
  byte back[2];
  if (!wr1(REG_CONTROL, ctl) || !wr1(RAM_END, last) || !rd(RAM_END, back, 2)) return;
  if (back[0] != last)                          setFail(RAM_END, last, back[0]);
  else if ((back[1] & 0xFC) != (ctl & 0xFC))    setFail(REG_CONTROL, ctl, back[1]);  // bits 1:0 are live flags
}

// Set a real date/time with the counter running (control = 0x00), the way the
// Minerva ROM does, then read it back and check every field.
#define DATE_SEC   0x56
static const byte dateSet[6] = {0x00, DATE_SEC, 0x34, 0x12, YD(2, 0x30), WM(6, 0x08)};  // 12:34:56 Sun 30 Aug y+2

static void dateTest() {
  if (!wr1(REG_CONTROL, 0x00) || !wr(REG_HUNDREDTH, dateSet, 6)) return;
  delay(DATE_SETTLE_MS);
  if (!rd(REG_HUNDREDTH, dateBack, 6)) return;
  // hundredths ignored; seconds may tick if a crystal is fitted
  byte sec = ((dateBack[1] >> 4) * 10) + (dateBack[1] & 0x0F);
  byte secMax = HAS_CRYSTAL ? 59 : 56;
  if (sec < 56 || sec > secMax) setFail(REG_SECONDS, DATE_SEC, dateBack[1]);
  for (byte i = 2; i < 6; i++)
    if (dateBack[i] != dateSet[i]) setFail(REG_HUNDREDTH + i, dateSet[i], dateBack[i]);
}

static void printDateBack() {
  // dd/mm y+N wdW hh:mm:ss from the raw registers
  printHex2(dateBack[4] & 0x3F); Serial.print('/');
  printHex2(dateBack[5] & 0x1F);
  Serial.print(F(" y+")); Serial.print(dateBack[4] >> 6);
  Serial.print(F(" wd")); Serial.print(dateBack[5] >> 5);
  Serial.print(' ');
  printHex2(dateBack[3] & 0x3F); Serial.print(':');
  printHex2(dateBack[2]);        Serial.print(':');
  printHex2(dateBack[1]);
}

// ---------------------------------------------------------------- OSCI-driven tests

// The Nano drives OSCI at OSC_HZ with the chip in 50 Hz mode, so the counter
// chain runs OSC_HZ/50 times faster than real time. Nothing may print between
// a clock write and its read-back: a blocking Serial.print would eat the margin.

#if HAS_OSC_DRIVE

// Stopped and driven for 3.5 chip seconds, the clock must not move.
static void stopTest() {
  const byte set[2] = {0x00, 0x58};
  byte back[2];
  if (!wr1(REG_CONTROL, CTL_STOP | CTL_50HZ) || !wr(REG_HUNDREDTH, set, 2)) return;
  delay(CHIP_MS(35));
  if (!rd(REG_HUNDREDTH, back, 2)) return;
  if (back[1] != 0x58) setFail(REG_SECONDS, 0x58, back[1]);
  if (back[0] != 0x00) setFail(REG_HUNDREDTH, 0x00, back[0]);
}

// Each case is loaded with the counter stopped and released, which resets the
// divider, so after 2.5 chip seconds the seconds read exactly 00.
struct RollCase { byte sec, min, hour, yd, wm, eMin, eHour, eYd, eWm; };
static const RollCase rollCases[] PROGMEM = {
  {0x58, 0x34, 0x12, YD(2, 0x30), WM(0, 0x08), 0x35, 0x12, YD(2, 0x30), WM(0, 0x08)}, // 1 minute
  {0x58, 0x59, 0x12, YD(2, 0x30), WM(0, 0x08), 0x00, 0x13, YD(2, 0x30), WM(0, 0x08)}, // 2 hour
  {0x58, 0x59, 0x23, YD(2, 0x30), WM(0, 0x04), 0x00, 0x00, YD(2, 0x01), WM(1, 0x05)}, // 3 30-day month
  {0x58, 0x59, 0x23, YD(2, 0x31), WM(0, 0x05), 0x00, 0x00, YD(2, 0x01), WM(1, 0x06)}, // 4 31-day month
  {0x58, 0x59, 0x23, YD(1, 0x28), WM(0, 0x02), 0x00, 0x00, YD(1, 0x01), WM(1, 0x03)}, // 5 Feb non-leap
  {0x58, 0x59, 0x23, YD(0, 0x28), WM(0, 0x02), 0x00, 0x00, YD(0, 0x29), WM(1, 0x02)}, // 6 Feb leap
  {0x58, 0x59, 0x23, YD(3, 0x31), WM(0, 0x12), 0x00, 0x00, YD(0, 0x01), WM(1, 0x01)}, // 7 year end
};
#define N_ROLL (sizeof(rollCases) / sizeof(rollCases[0]))

// Failure address for roll: (case number << 4) | register
static void rollFail(byte c, byte reg, byte expect, byte got) {
  setFail(((c + 1) << 4) | reg, expect, got);
}

static void rollTest() {
  for (byte c = 0; c < N_ROLL; c++) {
    RollCase rc;
    memcpy_P(&rc, &rollCases[c], sizeof(rc));
    byte set[6] = {0x00, rc.sec, rc.min, rc.hour, rc.yd, rc.wm};
    if (!wr1(REG_CONTROL, CTL_STOP | CTL_50HZ) || !wr(REG_HUNDREDTH, set, 6)) return;
    if (!wr1(REG_CONTROL, CTL_50HZ)) return;   // release: divider starts from zero
    delay(CHIP_MS(25));
    byte back[5];   // sec, min, hour, yd, wm
    if (!rd(REG_SECONDS, back, 5)) return;
    if (back[0] != 0x00)     rollFail(c, REG_SECONDS,  0x00,     back[0]);
    if (back[1] != rc.eMin)  rollFail(c, REG_MINUTES,  rc.eMin,  back[1]);
    if (back[2] != rc.eHour) rollFail(c, REG_HOURS,    rc.eHour, back[2]);   // full byte: format bits too
    if (back[3] != rc.eYd)   rollFail(c, REG_YEARDATE, rc.eYd,   back[3]);
    if (back[4] != rc.eWm)   rollFail(c, REG_WDMONTH,  rc.eWm,   back[4]);
  }
}

// Arm a daily alarm at almMin:almHour with the clock at 12:34:58, wait 3.5
// chip seconds, return the control register (flag bits included).
static bool alarmRun(byte almHour, byte almMin, byte *ctlBack) {
  const byte clk[6] = {0x00, 0x58, 0x34, 0x12, YD(2, 0x30), WM(0, 0x08)};
  const byte alm[5] = {ALM_DAILY, 0x00, 0x00, almMin, almHour};   // alarm ctl, hund, sec, min, hour
  if (!wr1(REG_CONTROL, CTL_STOP | CTL_50HZ)) return false;
  if (!wr(REG_HUNDREDTH, clk, 6) || !wr(REG_ALARM_CTL, alm, 5)) return false;
  if (!wr1(REG_CONTROL, CTL_50HZ | CTL_ALARM_EN)) return false;   // release, flags cleared
  if (!rd(REG_CONTROL, ctlBack, 1)) return false;
  if (*ctlBack & CTL_ALARM_FLG) return true;                       // set too early: caller fails it
  delay(CHIP_MS(35));
  return rd(REG_CONTROL, ctlBack, 1);
}

static void alarmTest() {
  byte ctl;
  // positive: alarm at 12:35:00, two chip seconds away, must fire
  if (!alarmRun(0x12, 0x35, &ctl)) return;
  if (!(ctl & CTL_ALARM_FLG)) { setFail(REG_CONTROL, CTL_50HZ | CTL_ALARM_EN | CTL_ALARM_FLG, ctl); return; }
  // negative: alarm at 13:35:00, must not fire at 12:35:00
  if (!alarmRun(0x13, 0x35, &ctl)) return;
  if (ctl & CTL_ALARM_FLG) setFail(REG_CONTROL, CTL_50HZ | CTL_ALARM_EN, ctl);
}

// Timer preset to 98 counting seconds: after 3.5 chip seconds it has wrapped
// 99 -> 00 and reads 01 or 02, and the timer flag must be set.
static void timerTest() {
  byte back[1];
  if (!wr1(REG_CONTROL, CTL_STOP | CTL_50HZ)) return;
  if (!wr1(REG_ALARM_CTL, ALM_TMR_SEC) || !wr1(REG_TIMER, 0x98)) return;
  if (!wr1(REG_CONTROL, CTL_50HZ | CTL_ALARM_EN)) return;   // release, flags cleared
  delay(CHIP_MS(35));
  if (!rd(REG_TIMER, back, 1)) return;
  if (back[0] != 0x01 && back[0] != 0x02) setFail(REG_TIMER, 0x01, back[0]);
  if (!rd(REG_CONTROL, back, 1)) return;
  if (!(back[0] & CTL_TIMER_FLG)) setFail(REG_CONTROL, CTL_50HZ | CTL_ALARM_EN | CTL_TIMER_FLG, back[0]);
}

#endif  // HAS_OSC_DRIVE

// ---------------------------------------------------------------- TIME test

static void timeTest() {
#if HAS_CRYSTAL
  const byte t[4] = {0x00, 0x56, 0x34, 0x12};  // hundredths, sec, min, hours (BCD 12:34:56)
  byte back;
  if (!wr1(REG_CONTROL, CTL_STOP) || !wr(REG_HUNDREDTH, t, 4) || !wr1(REG_CONTROL, 0x00)) return;
  delay(2500);
  if (!rd(REG_SECONDS, &back, 1)) return;
  byte sec = ((back >> 4) * 10) + (back & 0x0F);
  if (sec < 58 || sec > 59) setFail(REG_SECONDS, 0x58, back);
#else
  results[T_TIME].status = S_NT;
#endif
}

// ---------------------------------------------------------------- cleanup

// Stop the counter, zero 0x01..0xFF, read it back, then control = 0x00.
static void cleanTest() {
  byte buf[CHUNK];
  if (!wr1(REG_CONTROL, CTL_STOP)) return;
  memset(buf, 0, sizeof buf);
  for (int addr = REG_HUNDREDTH; addr <= RAM_END; addr += CHUNK) {
    byte n = min((int)CHUNK, RAM_END - addr + 1);
    if (!wr(addr, buf, n)) return;
  }
  for (int addr = REG_HUNDREDTH; addr <= RAM_END; addr += CHUNK) {
    byte n = min((int)CHUNK, RAM_END - addr + 1);
    if (!rd(addr, buf, n)) return;
    for (byte i = 0; i < n; i++)
      if (buf[i] != 0x00) setFail(addr + i, 0x00, buf[i]);
  }
  wr1(REG_CONTROL, 0x00);
}

// ---------------------------------------------------------------- report
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
void loop() {
  static byte idlePolls = 0;

  if (busTimedOut()) {
    busClear();
    Serial.println(F("! I2C bus timeout - bus cleared"));
  }

  bool low  = chipPresent(ADDR_A0_LOW);
  bool high = chipPresent(ADDR_A0_HIGH);
  if (!low && !high) {
    if (++idlePolls >= HEARTBEAT_POLLS) { idlePolls = 0; Serial.print('.'); }
    delay(POLL_MS);
    return;
  }
  idlePolls = 0;

  // debounce: the chip must still answer after the contacts have settled
  delay(SETTLE_MS);
  low  = chipPresent(ADDR_A0_LOW);
  high = chipPresent(ADDR_A0_HIGH);
  if (!low && !high) return;

  dev = low ? ADDR_A0_LOW : ADDR_A0_HIGH;
  bothAddr = low && high;
  runChip();

  while (chipPresent(ADDR_A0_LOW) || chipPresent(ADDR_A0_HIGH)) delay(POLL_MS);
  delay(POLL_MS);
  Serial.println(F("insert next chip"));
}

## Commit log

2026-08-30 Minerva MK II Reimagined, SMD edition, with PCF8583 tester
    [QL_Minerva_MK2-B_Cu.gbr, QL_Minerva_MK2-B_Mask.gbr, QL_Minerva_MK2-B_Paste.gbr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]
2026-08-30 Title blocks: copyright Arley Silveira, credit to Alvaro Alea Fernandez, licence
    [QL_Minerva_MK2.kicad_pcb, QL_Minerva_MK2.kicad_sch, RTC Tester.kicad_pcb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]
2026-08-31 Add C5 10uF bulk capacitor on +5V
    [QL_Minerva_MK2-B_Cu.gbr, QL_Minerva_MK2-B_Mask.gbr, QL_Minerva_MK2-B_Paste.gbr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]
2026-08-31 Refill zones
    [QL_Minerva_MK2.kicad_pcb]

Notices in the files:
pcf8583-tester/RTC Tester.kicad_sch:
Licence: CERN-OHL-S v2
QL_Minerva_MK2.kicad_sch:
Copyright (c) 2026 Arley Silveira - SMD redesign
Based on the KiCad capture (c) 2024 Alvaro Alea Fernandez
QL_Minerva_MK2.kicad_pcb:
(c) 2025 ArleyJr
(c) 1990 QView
